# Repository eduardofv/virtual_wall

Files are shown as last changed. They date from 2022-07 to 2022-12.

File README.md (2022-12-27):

# Roomba-like Virtual Wall

## Description

This is an old project that I've been using at home for a couple of years. Sorry for not having all the references I originally used to develop this, I'll try to update as soon as possible.

Many of this things are pretty rough, specially the PCB and the 3D printed enclosure as it was my first model. Hope this can help anyone interested.

- Arduino based code for ATTiny85 controller, a IR Led and a standard white led for status
- Used a MT3608 voltage booster and 2 or 3 AA/AAA batteries
- PCB dessigned with Freecad, DIYed at home (2.5x5cm copper PBC)
- Programmed the uC with Arduino (1.8+) IDE. Download libraries for ATT85. Use Arduino UNO as ISP to program. Check references in code
- Enclosure designed in Blender and 3D printed on a Monoprice Select Mini v2 with black PLA

## TODO:

- Correct PCB wiring for LED Pin - checar en el prototipo 2
- Eliminar el algoritmo del led para indicar nivel de batería - no funciona bien
- Generar nueva version (v3)
- Documento de descripción del proyecto, referencias a proyectos originales
- Fotos / Video

## Changelog

- 2022-12-27:  New version with no VDC monitoring. Uses TP4056 + 18650 battery
- Started 2020
## Resources

-

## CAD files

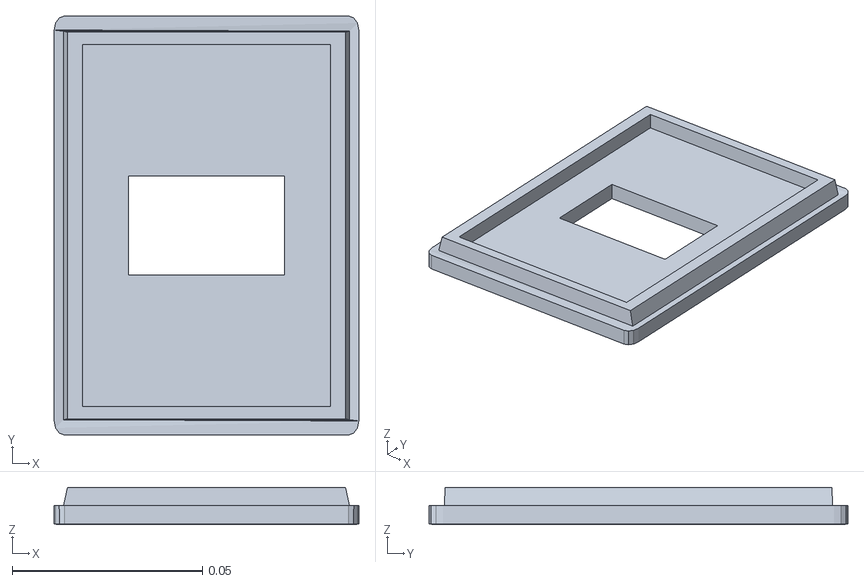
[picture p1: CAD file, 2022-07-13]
3d/virtual_wall-Tapa_003.stl
0.08 x 0.11 x 0.00974

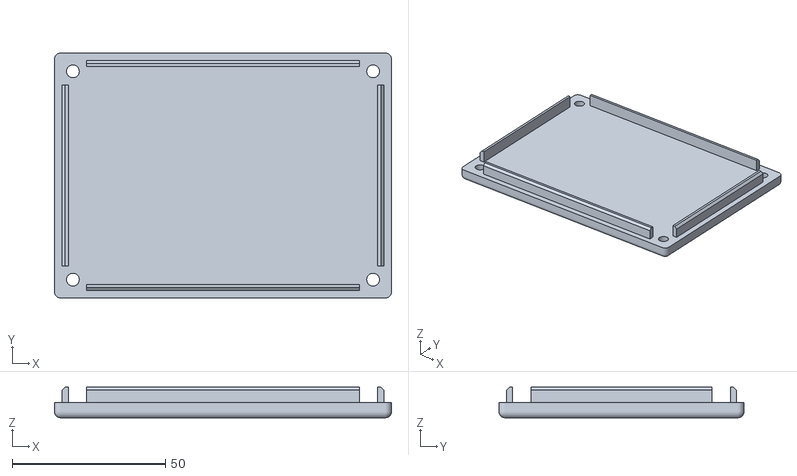
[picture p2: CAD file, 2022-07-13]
3d/freecad-tapa.stl
110.0 x 80.0 x 10.0

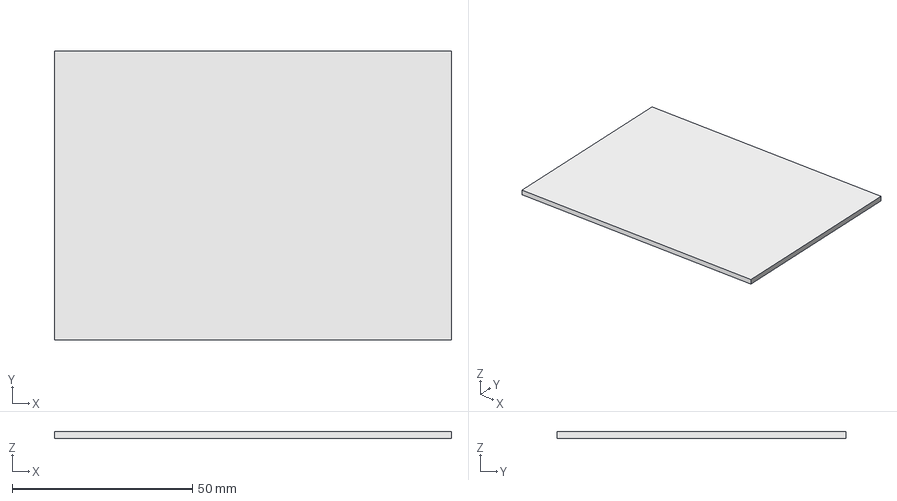
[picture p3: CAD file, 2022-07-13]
3d/v_w-tapa-paso 1.FCStd
110.0 x 80.0 x 2.00 mm

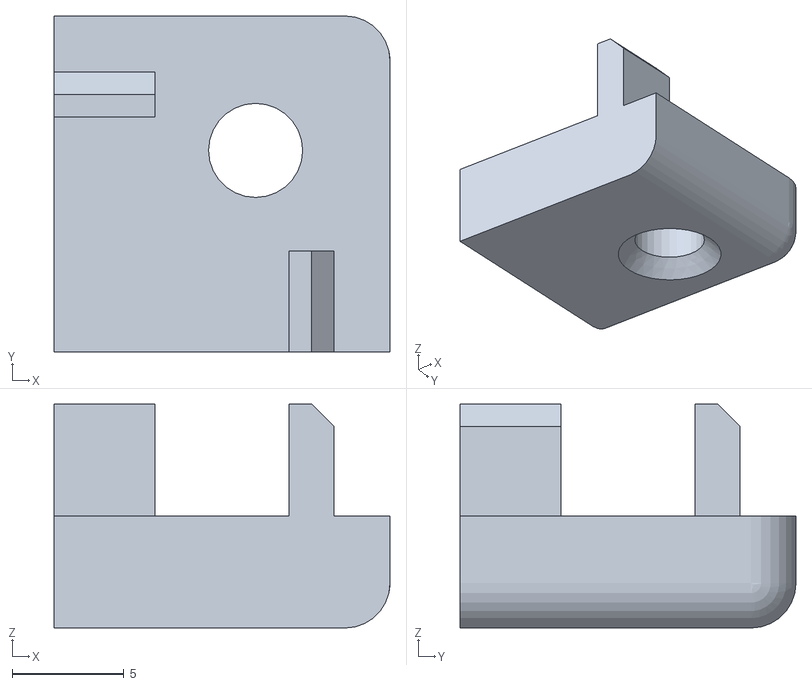
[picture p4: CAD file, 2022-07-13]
3d/prueba_tapa_tornillo.stl
15.0 x 15.0 x 10.0

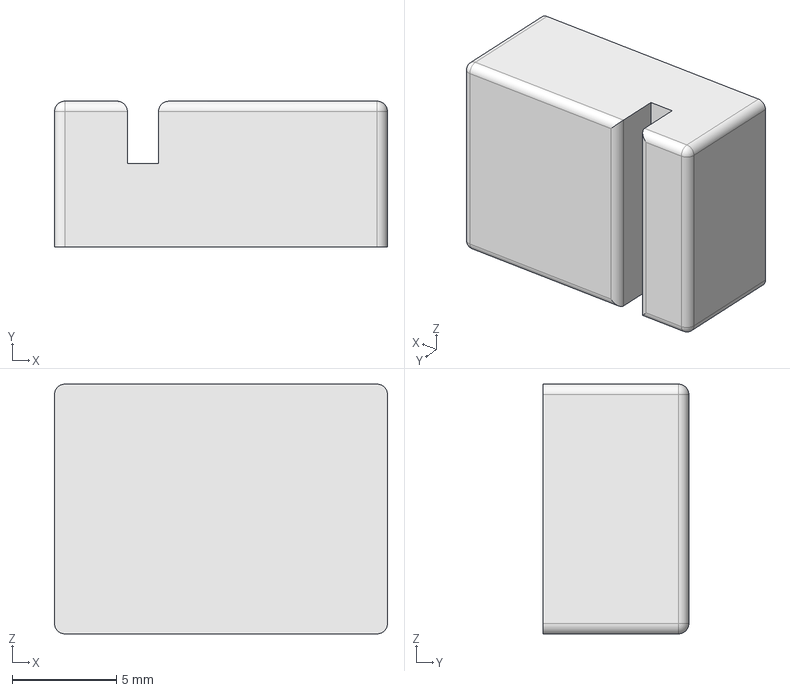
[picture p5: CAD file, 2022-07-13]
3d/soporte pcb.FCStd
16.0 x 7.00 x 12.0 mm

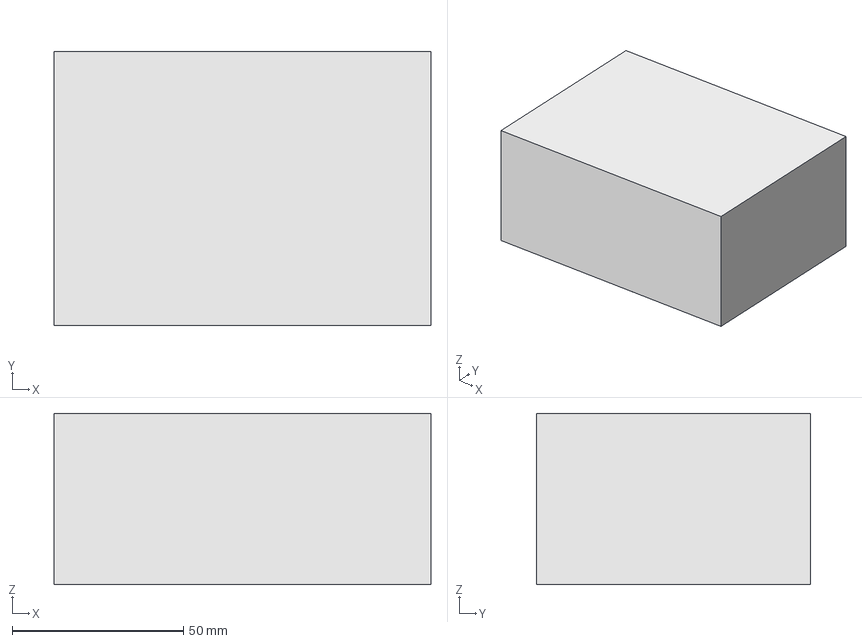
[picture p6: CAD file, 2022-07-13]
3d/virtual_wall_fc-paso 3.FCStd
110.0 x 80.0 x 50.0 mm

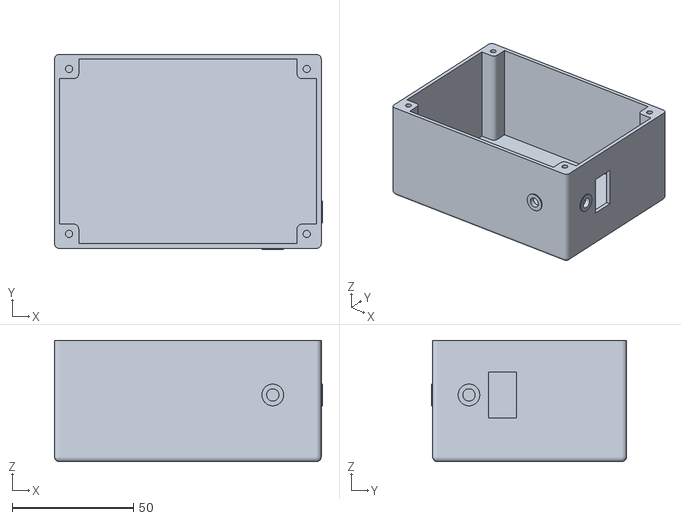
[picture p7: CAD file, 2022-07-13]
3d/caja.stl
110.5 x 80.5 x 50.0

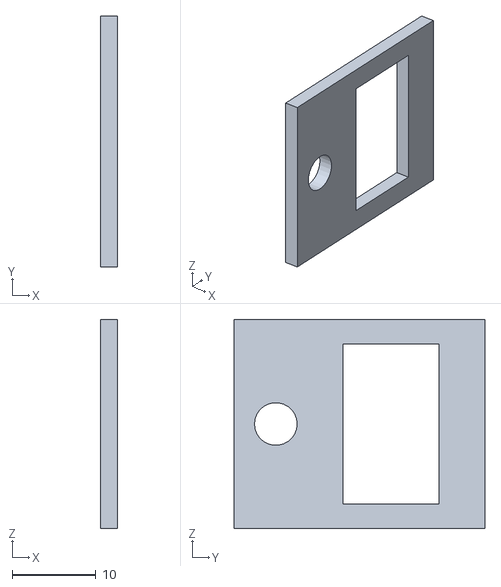
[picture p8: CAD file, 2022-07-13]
3d/prueba_espacios_led_switch.stl
2.00 x 30.0 x 25.0

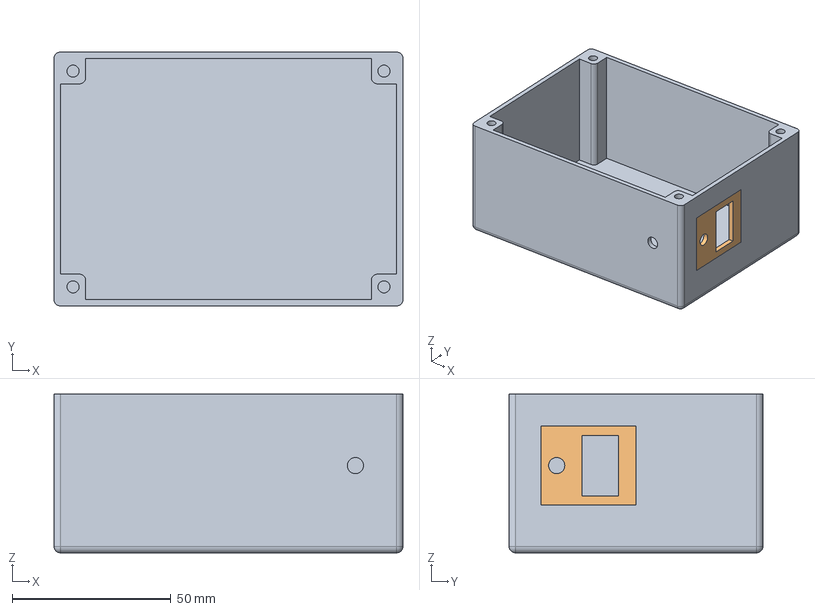
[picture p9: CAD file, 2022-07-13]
3d/virtual_wall_fc-tests.FCStd
110.0 x 80.0 x 50.0 mm

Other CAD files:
3d/virtual_wall-Tapa_002.stl
3d/v_w-tapa-paso 5.FCStd
3d/tapa.stl
3d/virtual_wall_fc.FCStd
3d/v_w-tapa-tests.FCStd
3d/virtual_wall_fc-paso 4.FCStd
3d/freecad-caja.stl
3d/v_w-tapa-paso 6.FCStd
3d/virtual_wall_fc-paso 5.FCStd
3d/led padder.FCStd
3d/led padder.stl
3d/old/led padder.FCStd
3d/old/v_w-tapa-paso 2.FCStd
3d/old/v_w-tapa-paso 4.FCStd
3d/old/v_w-tapa-paso 5.FCStd
3d/old/v_w-tapa-paso 6.FCStd
3d/old/v_w-tapa-tests.FCStd
3d/old/virtual_wall_fc-paso 2.FCStd
3d/old/virtual_wall_fc-paso 4.FCStd
3d/old/virtual_wall_fc-paso 5.FCStd
3d/old/virtual_wall_fc-tests-screw.FCStd
3d/old/virtual_wall_fc.FCStd
3d/prueba_caja_tornillo.stl
3d/soporte pcb.stl
3d/v_w-tapa-paso 2.FCStd
3d/v_w-tapa-paso 4.FCStd
3d/virtual_wall.blend
3d/virtual_wall_fc-paso 2.FCStd
3d/virtual_wall_fc-tests-screw.FCStd
3d/virtual_wall_modelo.blend

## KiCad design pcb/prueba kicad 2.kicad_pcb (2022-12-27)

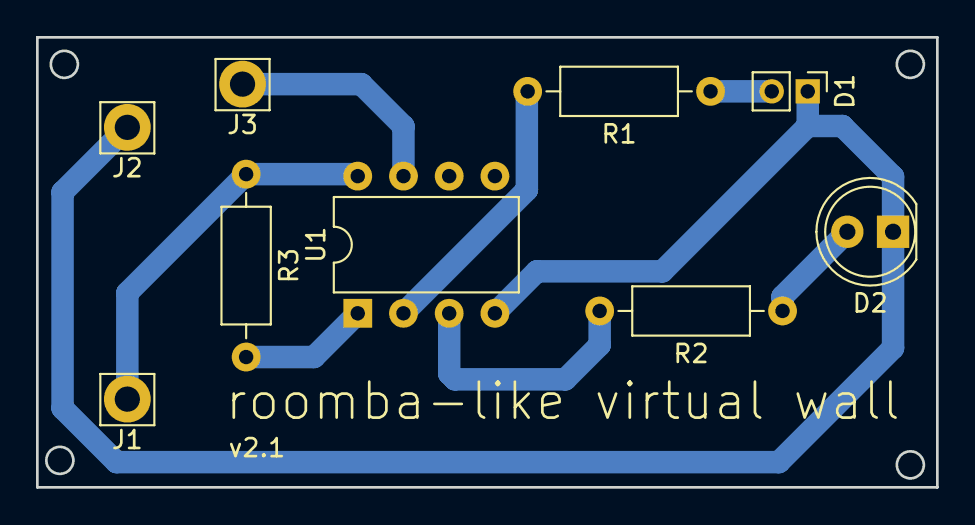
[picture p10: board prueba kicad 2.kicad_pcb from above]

Board: 2 copper layers, 50.0 x 25.0 mm, 9 parts (0 on the bottom side), 8 nets.

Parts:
D1: LED; PinHeader_1x02_P2.00mm_Vertical
D2: IR LED; LED_D5.0mm
J1: +5V; Pin_D1.4mm_L8.5mm_W2.8mm_FlatFork
J2: GND; Pin_D1.4mm_L8.5mm_W2.8mm_FlatFork
J3: Battery Level; Pin_D1.4mm_L8.5mm_W2.8mm_FlatFork
R1: 2.2K; R_Axial_DIN0207_L6.3mm_D2.5mm_P10.16mm_Horizontal
R2: 47; R_Axial_DIN0207_L6.3mm_D2.5mm_P10.16mm_Horizontal
R3: 10K; R_Axial_DIN0207_L6.3mm_D2.5mm_P10.16mm_Horizontal
U1: ATtiny85-20PU; DIP-8_W7.62mm

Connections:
+5V: J1.1, R3.1, U1.8
GND: D1.1, D2.1, J2.1, U1.4
unnamed: D1.2, R1.1
unnamed: D2.2, R2.1
unnamed: J3.1, U1.7
unnamed: R1.2, U1.2
unnamed: R2.2, U1.3
unnamed: R3.2, U1.1

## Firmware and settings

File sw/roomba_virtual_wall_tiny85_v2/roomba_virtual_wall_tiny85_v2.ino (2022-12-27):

// attiny low power mode http://www.technoblogy.com/show?KX0
//prepare arduino uno as isp programmer https://highlowtech.org/?p=1706
//  - burn the ISP programmer sketch
//attiny programming http://highlowtech.org/?p=1695
//  - install boards
//  - select boards, ATTiny uc
//  - select processor attiny85
//  - set clock at 8 MHz Internal
//    - El primer attiny lo tengo que poner a 8Mhz pero el segundo a 1Mhz ??!!
//    - 20221227 - Al parecer debe correr a 1Mhz. Seleccionar Tools/Clock Internal 1MHz/Burn bootloader
//  * compile
// ** Use original Arduino UNO
// attiny85 pinout https://nerdytechy.com/attiny85-microcontroller-guide/

#include <avr/pgmspace.h>
#include <avr/sleep.h>

#include "tiny_IRremote.h"
#include "tiny_IRremoteInt.h"

#define LED_PIN           3  //Arduino pin 0 == ATTiny85 physical pin 5 para el prototipo 2
                             //Arduino pin 3 == ATTiny85 physical pin 2 para el prototipo 1
#define IR_LED_PIN        38 //Arduino pin 4? == ATTiny85 physical pin 3
#define BAT_LEVEL_PIN     2 //"P2", physical
#define BAT_LEVEL_INPUT   1 //Corresponds to PIN_2, physical 7 
//#define MAX_TIME_SEC      40 //Test
#define MAX_TIME_SEC      2 * 60 * 60 //Max run time in seconds. Will shutdown after this time (2h)

//En el ATTiny el indicador aún no funciona como quisiera
//BEGIN GENERATED CODE
//LED levels lookup table generated in `generate_led_levels.py`
#define VMAX              3.3
#define VMIN              2.0
#define MIN_LED           128
#define LED_HIGH_PERIOD   75
#define LED_TOTAL_PERIOD  1000
#define VOLTAGE_SPREAD    5
#define STEPS_PER_PERIOD  5
#define COUNTER_DIVIDER   15
#define VOLTAGE_INDEX(v)  ((v) - 2.0) * 3

const PROGMEM uint8_t LED_LEVELS[] = {0x19,0x33,0x4d,0x66,0x80,0x80,0x26,0x4c,0x73,0x99,0x9a,0x9a,0x3b,0x77,0xb3,0xb3,0xb3,0xb3,0x65,0xcb,0xcd,0xcd,0xcd,0xcd,0xe3,0xe6,0xe6,0xe6,0xe6,0xe6,0xff,0xff,0xff,0xff,0xff,0xff};
//END GENERATED CODE

// Utility macro
#define adc_disable() (ADCSRA &= ~(1<<ADEN)) // disable ADC (before power-off)

IRsend irsend;
unsigned int counter = 0;
int last_led_val = 0;


void setup() {
  //TCCR0B = TCCR0B & 0b11111000 | 0b001;
  pinMode(LED_PIN, OUTPUT);
  pinMode(BAT_LEVEL_PIN, INPUT);
  irsend.enableIROut(IR_LED_PIN);
  set_sleep_mode(SLEEP_MODE_PWR_DOWN);
}


void send_beacon() {
  irsend.mark(1000);
  irsend.space(1000);
}


void enter_sleep(void) {
  //Sleep mode decreses current from ~40mA to ~14mA in my circuit
  //  voltage booster still uses quite some energy, though
  //  maybe later build a latching circuit 
  
  //Shutdown notification
  for(int i=0; i<50; i++){
    digitalWrite(LED_PIN, 0);
    delay(100);
    digitalWrite(LED_PIN, 1);
    delay(100);
  }
  
  adc_disable();
  digitalWrite(LED_PIN, 0);

  sleep_enable();
  sleep_cpu();
}


float read_battery_voltage() {
  int sensorValue = analogRead(BAT_LEVEL_INPUT);
  // Convert the analog reading (which goes from 0 - 1023) to a voltage (0 - 5V):
  float voltage = sensorValue * (5.0 / 1023.0);
  return voltage;
}


void update_led_status(float v1) {
  counter += 1;
  int led_val = 0;
  if (counter <= LED_HIGH_PERIOD) {
    /* this is the calculation, but check in generate_led_levels.py
    v1 = constrain(v1, VMIN, VMAX);
    float vpdiff = (VMAX - v1) / VRANGE;
    float level = vpdiff + 0.01;
    float max_led = 255.0 * (1 - vpdiff);
    led_val = min(max_led, max_led * counter / (level * LED_HIGH_PERIOD));
    */

    v1 = constrain(v1, VMIN, VMAX);
    int counter_index = counter / COUNTER_DIVIDER;
    int vol_index = VOLTAGE_INDEX(v1);
    int led_val_index = vol_index * (1 + STEPS_PER_PERIOD) + counter_index;
    led_val = pgm_read_byte_near(led_val_index);
  }

  if(last_led_val != led_val) {
    analogWrite(LED_PIN, led_val);
    last_led_val = led_val;
  }
  
  if (counter > LED_TOTAL_PERIOD)
    counter = 0;
}


void loop() {
  send_beacon();
  //float v1 = read_battery_voltage();
  update_led_status(5.0);
  if(millis() > ((unsigned long)(MAX_TIME_SEC) * 1000))
    enter_sleep();
}

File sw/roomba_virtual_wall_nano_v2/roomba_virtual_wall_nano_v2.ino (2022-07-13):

#include <IRremote.h>
#include <ir_Lego_PF_BitStreamEncoder.h>

#define ENABLE_SERIAL_OUTPUT false

#define LED_PIN           5//2 //For tiny Arduino Pin 3 = Physical 2 on ATTiny85
#define IR_LED_PIN        38 //ATTiny85 physical pin 3, D3 on Nano
#define LED_HIGH_PERIOD   100
#define LED_TOTAL_PERIOD  1000
#define VMAX              3.3 //Alkaline bateries
#define VMIN              2.0 //MT3608 min operating voltage

// Initiate IRremote on Pin 3 (Physical)
IRsend irsend;
unsigned int counter = 0;
//bool led_high = true;

void setup()
{
  if (ENABLE_SERIAL_OUTPUT) {
    Serial.begin(9600);
  }

  pinMode(LED_PIN, OUTPUT);
  irsend.enableIROut(IR_LED_PIN);
}

void send_beacon() {
  irsend.mark(1000);
  irsend.space(1000);
}

float read_battery_voltage() {
  int sensorValue = analogRead(A0);
  // Convert the analog reading (which goes from 0 - 1023) to a voltage (0 - 5V):
  float voltage = sensorValue * (5.0 / 1023.0);
  if (ENABLE_SERIAL_OUTPUT) {
    //Serial.println(voltage);
  }
  return voltage;
}

void update_led_status(float v1) {
  counter += 1;
  if (counter <= LED_HIGH_PERIOD) {
    float led_val = 0;
    v1 = max(v1, VMIN);
    v1 = min(v1, VMAX);
    float vpdiff = (VMAX - v1) / (VMAX - VMIN);
    float level = vpdiff + 0.01;
    float max_led = 255.0 * (1 - vpdiff);
    led_val = min(max_led, max_led * counter / (level * LED_HIGH_PERIOD));
    if(ENABLE_SERIAL_OUTPUT)
      Serial.println(led_val);
    analogWrite(LED_PIN, led_val);
  }
  else {
    analogWrite(LED_PIN, 0);
  }
  if (counter > LED_TOTAL_PERIOD)
    counter = 0;
}

void loop()
{
  send_beacon();
  float v1 = read_battery_voltage();
  update_led_status(v1);
}

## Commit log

2022-07-13 Carga inicial
    [MSMV2E3D_untitled-Cube.3mf, caja.stl, freecad-caja.stl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]
2022-07-14 Updated timer shutdown
2022-07-14 Organized 3D files
    [MSMV2E3D_untitled-Cube.3mf, led padder.FCStd, soporte pcb.FCStd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]
2022-07-14 Deleted useless file
    [prueba kicad 2.kicad_pcb]
2022-07-14 Corrected type bugs in timeout for shutdown
    [roomba_virtual_wall_tiny85_v2.ino]
2022-07-14 Corrected type bugs in timeout for shutdown - prod version
    [roomba_virtual_wall_tiny85_v2.ino]
2022-12-27 Arreglar primer virtual wall que se echó la Trufa
    [prueba kicad 2.kicad_pcb]
2022-12-27 Update para versión de KiCAD
    [prueba kicad 2.kicad_sch]
